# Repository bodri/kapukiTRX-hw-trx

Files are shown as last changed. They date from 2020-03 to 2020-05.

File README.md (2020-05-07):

# Redundant RC transmitter module & 8 channel receiver
RC Receiver and transmitter module using redundant SX1280 RF modules.

The [firmware](https://github.com/bodri/kapukiTRX-fw-trx) is still under development, but you can take a look already...

[Please take a look at my previous project here](https://github.com/bodri/RcReceiver)

# Design
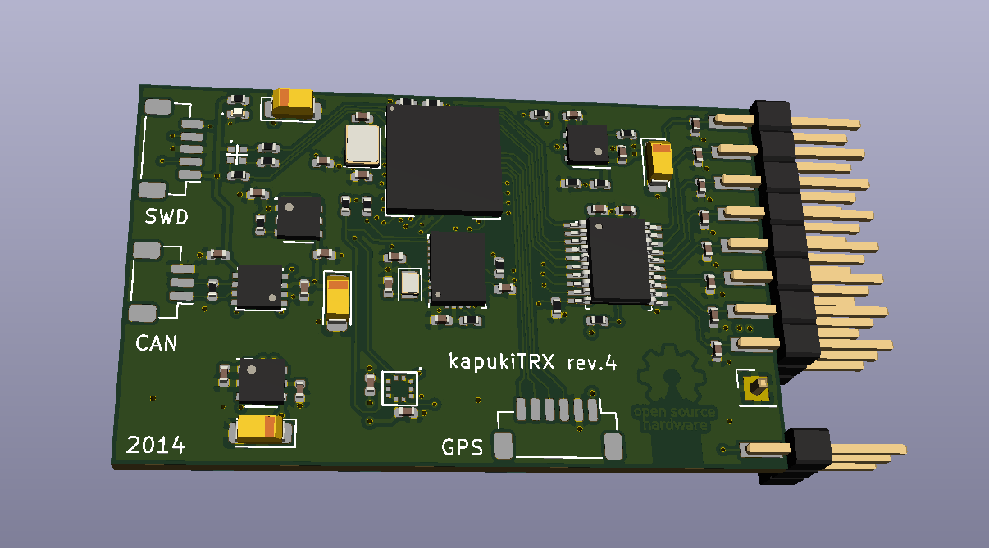
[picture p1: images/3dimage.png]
KiCAD 3D view


# Manufacturing
I would like to compare services from [OSHPark](http://oshpark.com)/[OSH Stencils](https://www.oshstencils.com) and [JLCPCB](http://jlcpcb.com), so I ordered:

| Manufacturer | Items | Price  | Order date | Shipped | Received | Total days |
|---|---|---|---|---|---|---|
| OSHPark | 3 PCBs | $19.80 | 09/11/2019 | 21/11/2019** | 17/12/2019 | 21 (35)**  |
| OSH Stencils | 1 stencil | $21.60 | 09/11/2019 | 12/11/2019 | 19/11/2019 | 10 |
| JLCPCB | 10 PCBs + stencil | $28.33 | 09/11/2019 | 14/11/2019 | 03/12/2019 | 21 |

<sub>** Originally was shipped on 21/11/2019 and received on the same day as the JLCPCB package, but I have received a message that the PCBs have "Severe over-etching in some regions" therefore not to use them. OSHPark refabricated them and I received the second batch on 17/12/2019.<sub>

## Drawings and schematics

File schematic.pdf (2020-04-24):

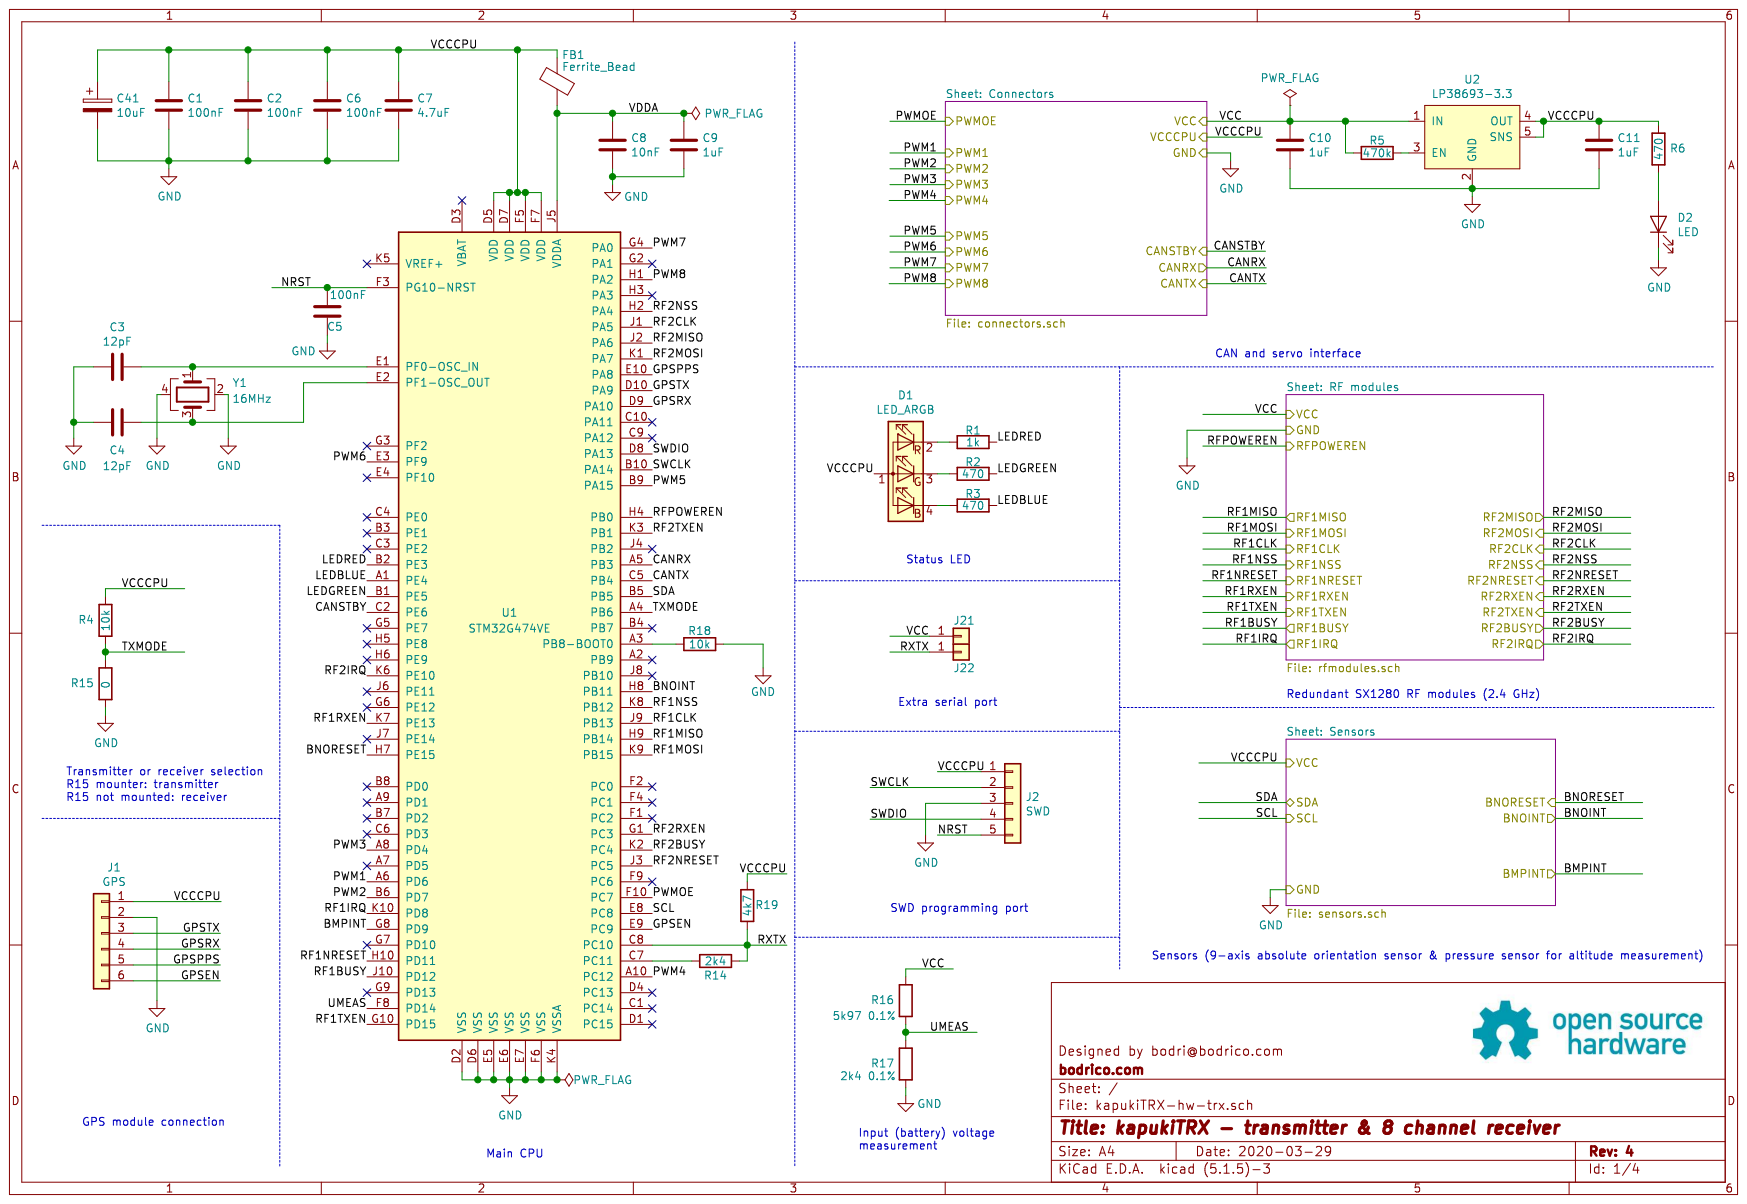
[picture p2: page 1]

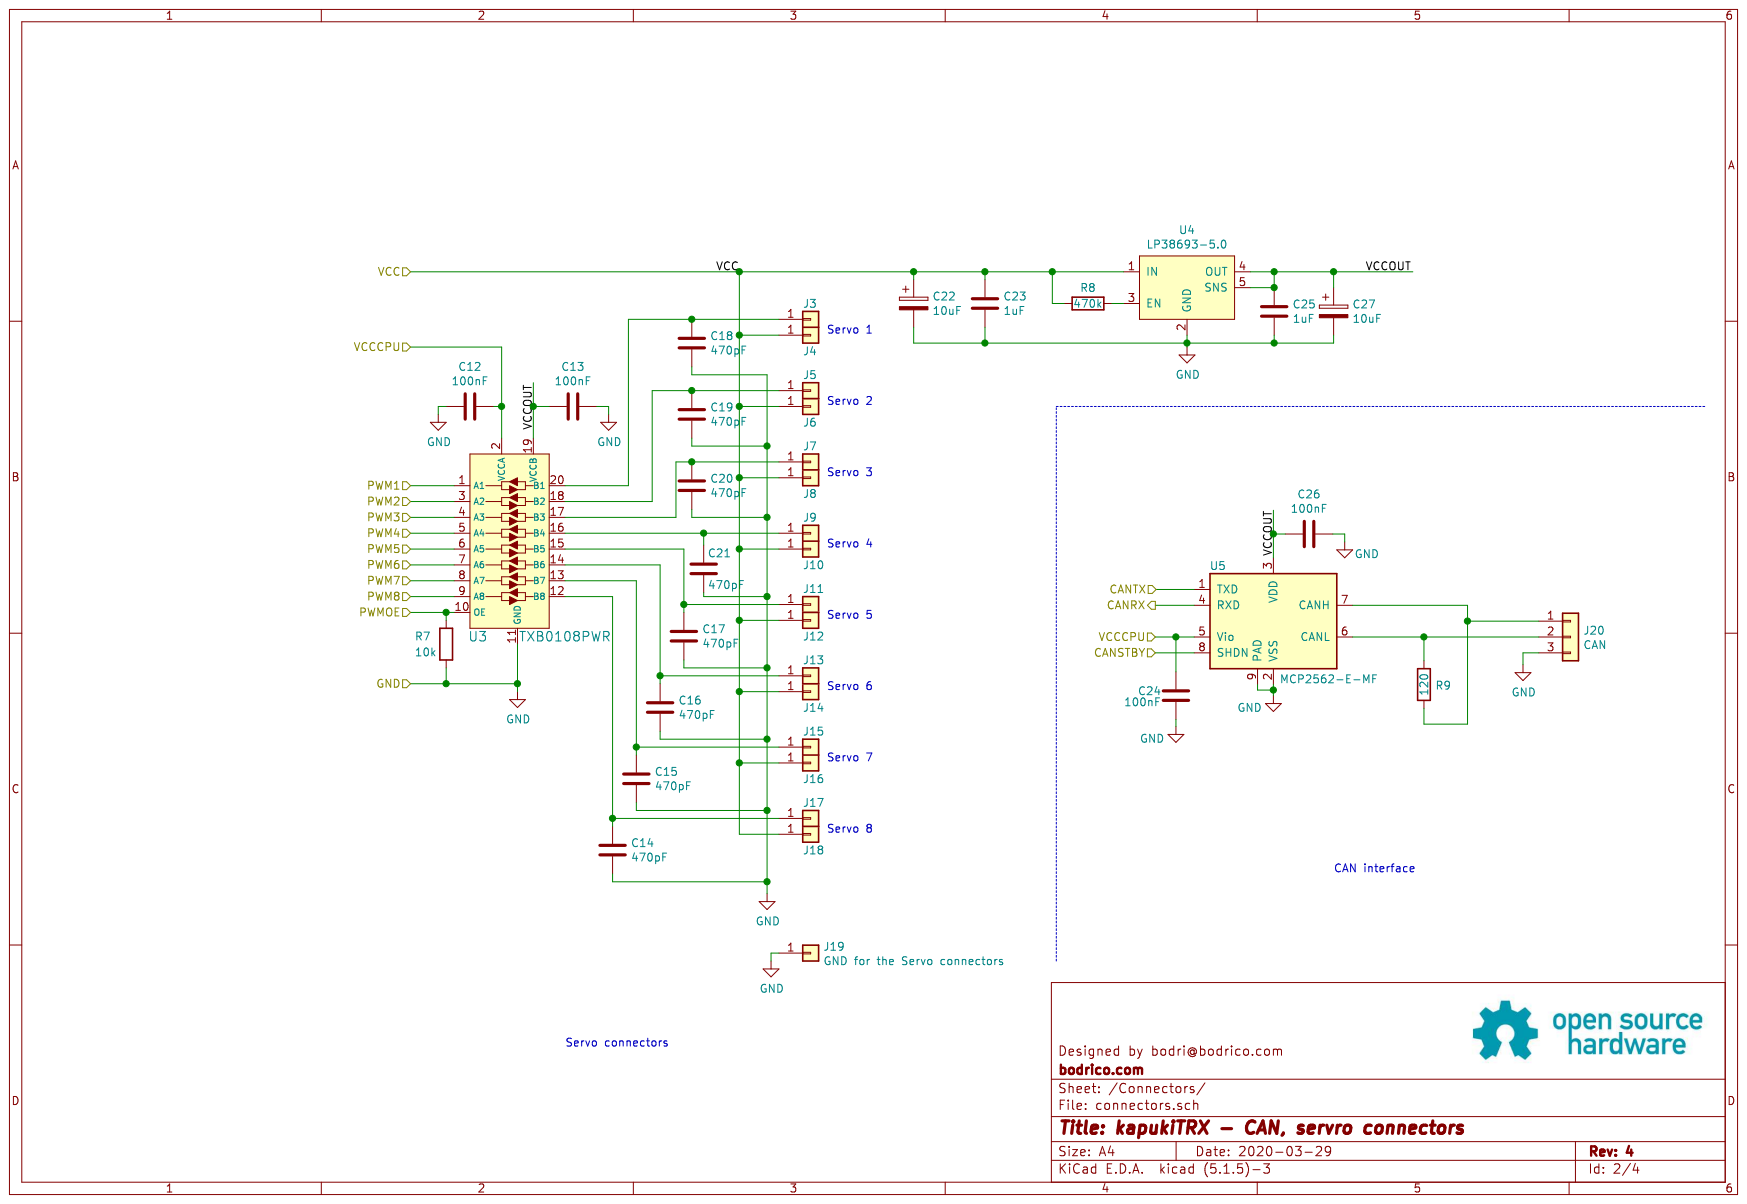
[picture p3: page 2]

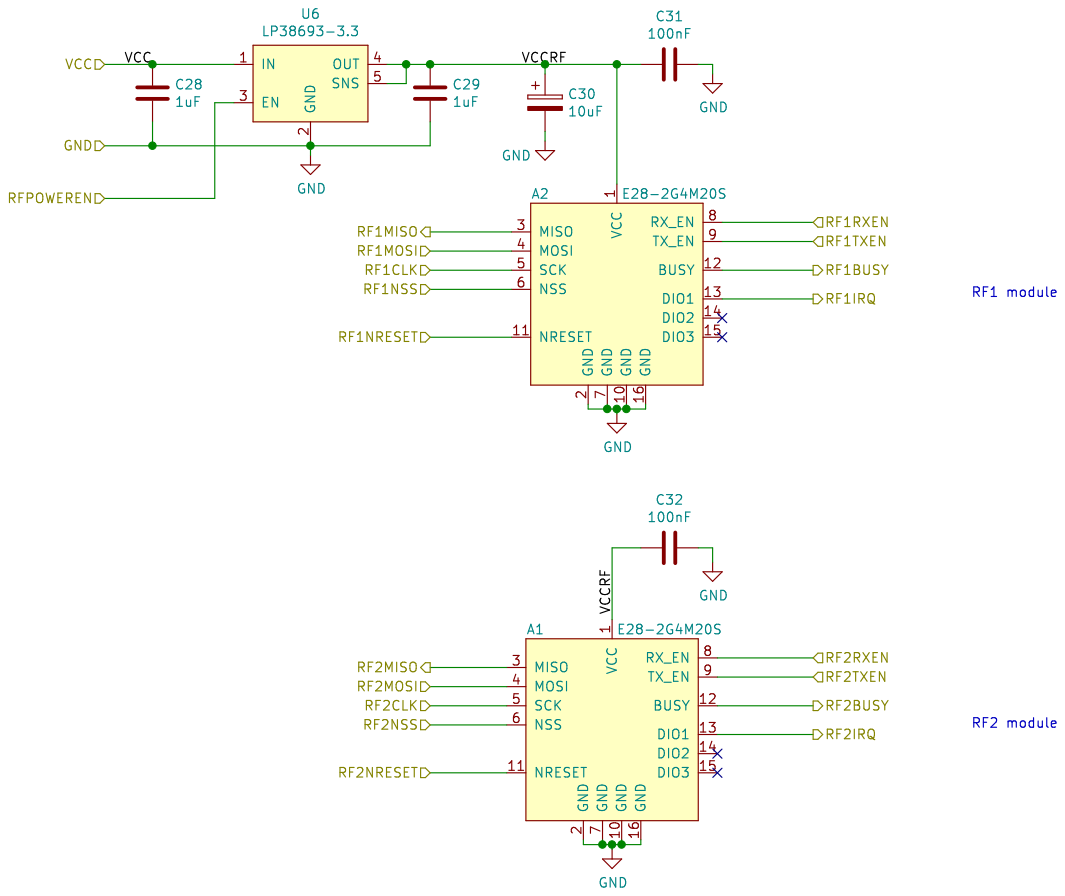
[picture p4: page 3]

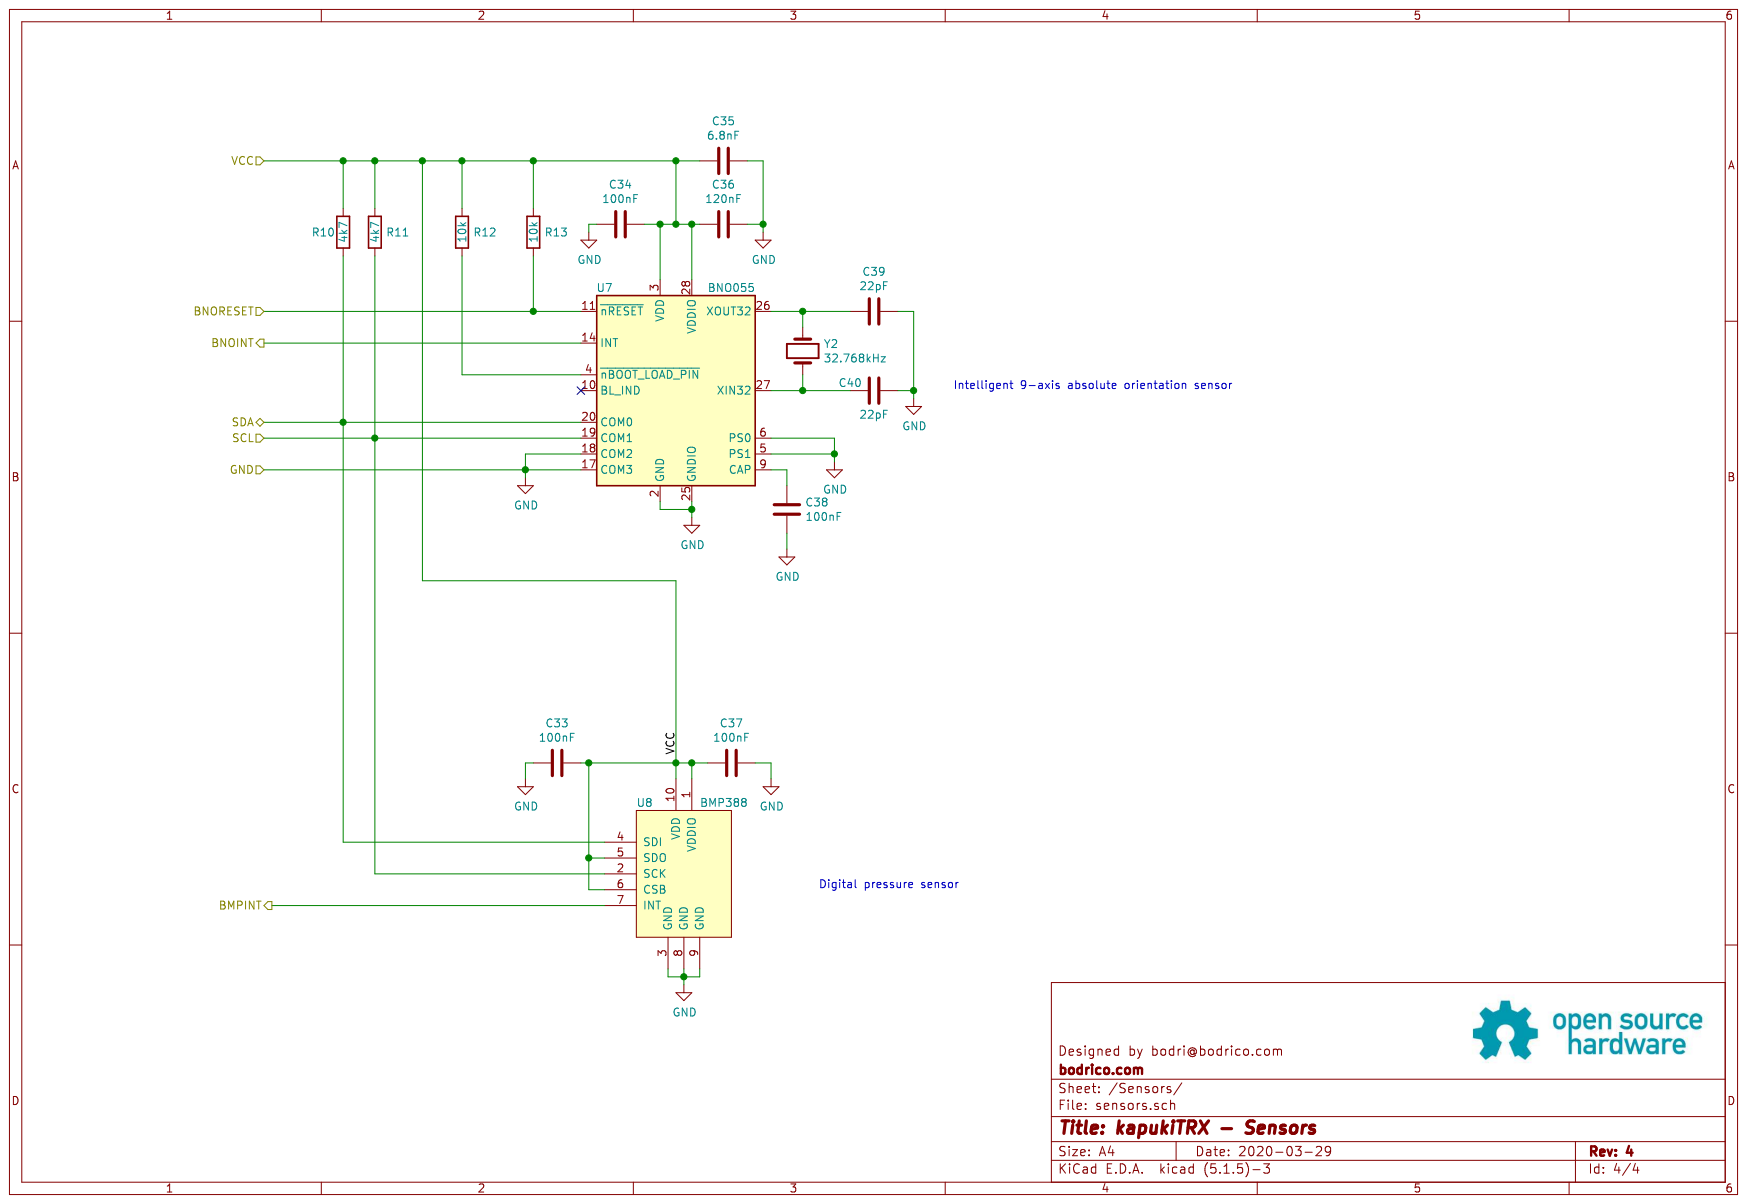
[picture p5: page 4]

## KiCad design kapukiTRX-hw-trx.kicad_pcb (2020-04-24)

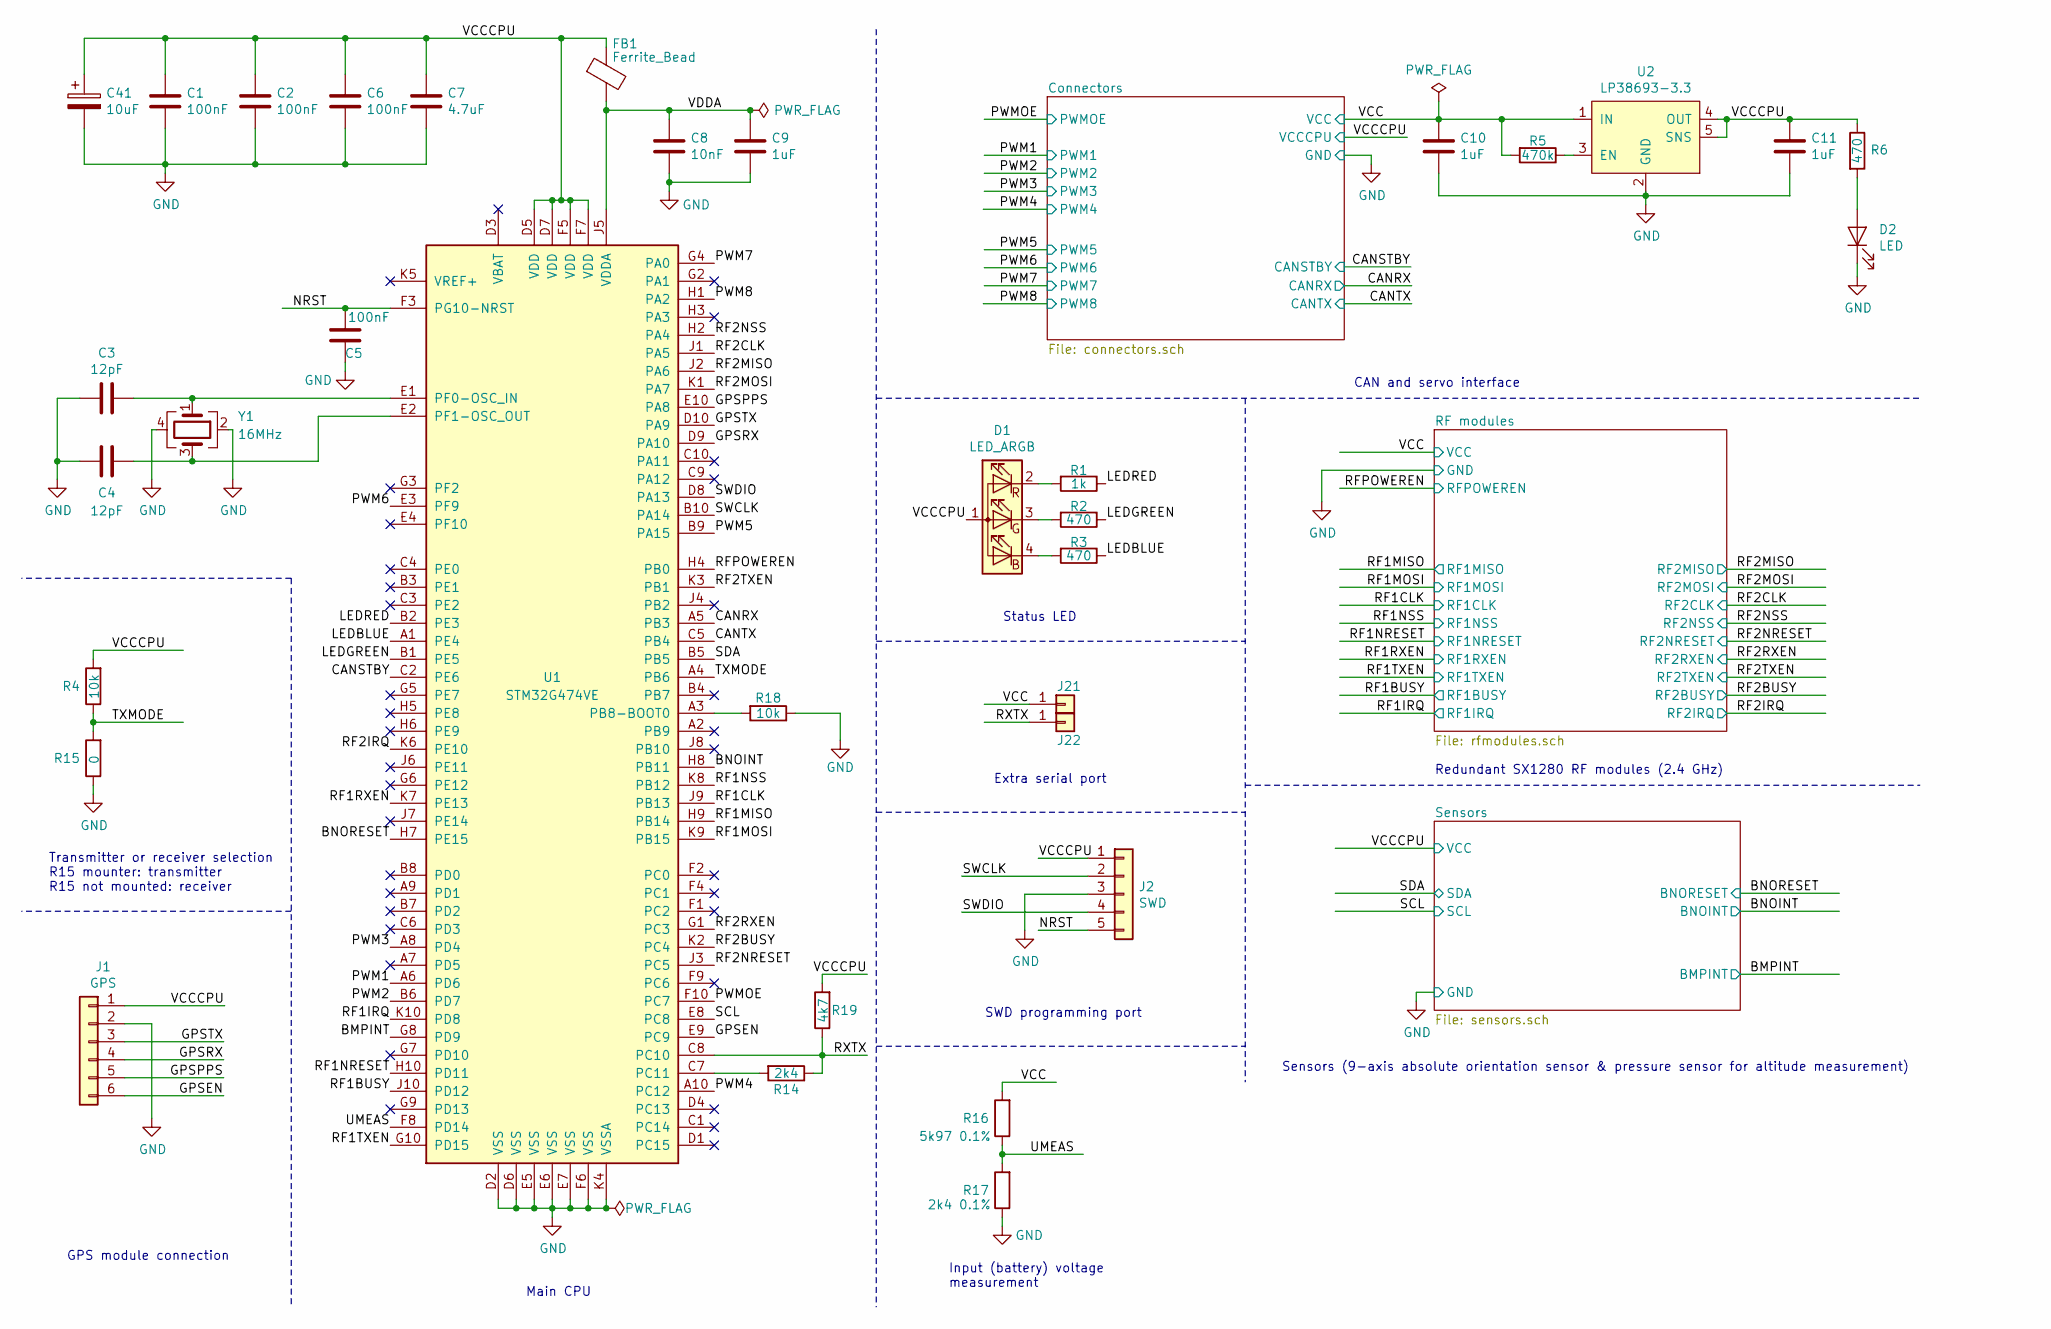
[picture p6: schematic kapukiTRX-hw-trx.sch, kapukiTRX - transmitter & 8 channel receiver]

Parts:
C1, C2, C5, C6: 100nF; C_0402_1005Metric
C3, C4: 12pF; C_0402_1005Metric
C7: 4.7uF; C_0402_1005Metric
C8: 10nF; C_0402_1005Metric
C9, C10, C11: 1uF; C_0402_1005Metric
C41: 10uF; CP_EIA-3216-18_Kemet-A
D1: LED_ARGB; LED_Lumex-LX0404
D2: LED; LED_0402_1005Metric
FB1: Ferrite_Bead; L_0402_1005Metric
J1: GPS; JST_SH_BM06B-SRSS-TB_1x06-1MP_P1.00mm_Vertical
J2: SWD; JST_SH_BM05B-SRSS-TB_1x05-1MP_P1.00mm_Vertical
J21, J22: Conn_01x01; PinHeader_1x01_P1.27mm
R1: 1k; R_0402_1005Metric
R2, R3, R6: 470; R_0402_1005Metric
R4, R18: 10k; R_0402_1005Metric
R5: 470k; R_0402_1005Metric
R14: 2k4; R_0402_1005Metric
R15: 0; R_0402_1005Metric
R16: 5k97 0.1%; R_0402_1005Metric
R17: 2k4 0.1%; R_0402_1005Metric
R19: 4k7; R_0402_1005Metric
U1: STM32G474VE; TFBGA-100_10x10_8.0x8.0mm
U2: LP38693-3.3; WSON-6_3x3mm_Pitch0.95mm
Y1: 16MHz; Oscillator_SMD_SeikoEpson_SG210-4Pin_2.5x2.0mm

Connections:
/BMPINT: U1.G8 (PD9); also elsewhere on the board
/BNOINT: U1.H8 (PB11); also elsewhere on the board
/BNORESET: U1.H7 (PE15); also elsewhere on the board
/CANRX: U1.A5 (PB3); also elsewhere on the board
/CANSTBY: U1.C2 (PE6); also elsewhere on the board
/CANTX: U1.C5 (PB4); also elsewhere on the board
/GPSEN: J1.6, U1.E9 (PC9)
/GPSPPS: J1.5, U1.E10 (PA8)
/GPSRX: J1.4, U1.D9 (PA10)
/GPSTX: J1.3, U1.D10 (PA9)
/LEDBLUE: R3.1, U1.A1 (PE4)
/LEDGREEN: R2.1, U1.B1 (PE5)
/LEDRED: R1.1, U1.B2 (PE3)
/NRST: C5.2, J2.5, U1.F3 (PG10-NRST)
/PWM1: U1.A6 (PD6); also elsewhere on the board
/PWM2: U1.B6 (PD7); also elsewhere on the board
/PWM3: U1.A8 (PD4); also elsewhere on the board
/PWM4: U1.A10 (PC12); also elsewhere on the board
/PWM5: U1.B9 (PA15); also elsewhere on the board
/PWM6: U1.E3 (PF9); also elsewhere on the board
/PWM7: U1.G4 (PA0); also elsewhere on the board
/PWM8: U1.H1 (PA2); also elsewhere on the board
/PWMOE: U1.F10 (PC7); also elsewhere on the board
/RF1BUSY: U1.J10 (PD12); also elsewhere on the board
/RF1CLK: U1.J9 (PB13); also elsewhere on the board
/RF1IRQ: U1.K10 (PD8); also elsewhere on the board
/RF1MISO: U1.H9 (PB14); also elsewhere on the board
/RF1MOSI: U1.K9 (PB15); also elsewhere on the board
/RF1NRESET: U1.H10 (PD11); also elsewhere on the board
/RF1NSS: U1.K8 (PB12); also elsewhere on the board
/RF1RXEN: U1.K7 (PE13); also elsewhere on the board
/RF1TXEN: U1.G10 (PD15); also elsewhere on the board
/RF2BUSY: U1.K2 (PC4); also elsewhere on the board
/RF2CLK: U1.J1 (PA5); also elsewhere on the board
/RF2IRQ: U1.K6 (PE10); also elsewhere on the board
/RF2MISO: U1.J2 (PA6); also elsewhere on the board
/RF2MOSI: U1.K1 (PA7); also elsewhere on the board
/RF2NRESET: U1.J3 (PC5); also elsewhere on the board
/RF2NSS: U1.H2 (PA4); also elsewhere on the board
/RF2RXEN: U1.G1 (PC3); also elsewhere on the board
/RF2TXEN: U1.K3 (PB1); also elsewhere on the board
/RFPOWEREN: U1.H4 (PB0); also elsewhere on the board
/RXTX: J22.1, R14.1, R19.1, U1.C8 (PC10)
/SCL: U1.E8 (PC8); also elsewhere on the board
/SDA: U1.B5; also elsewhere on the board
/SWCLK: J2.2, U1.B10 (PA14)
/SWDIO: J2.4, U1.D8 (PA13)
/TXMODE: R4.1, R15.2, U1.A4 (PB6)
/UMEAS: R16.1, R17.2, U1.F8 (PD14)
/VCCCPU: C1.1, C2.1, C6.1, C7.1, C11.1, C41.1, D1.1 (A), FB1.1, J1.1, J2.1, R4.2, R6.1, R19.2, U1.D5 (VDD), U1.D7 (VDD), U1.F5 (VDD), U1.F7 (VDD), U2.4 (OUT), U2.5 (SNS); also elsewhere on the board
/VDDA: C8.1, C9.1, FB1.2, U1.J5 (VDDA)
GND: C1.2, C2.2, C3.2, C4.2, C5.1, C6.2, C7.2, C8.2, C9.2, C10.2, C11.2, C41.2, D2.1 (K), J1.2, J2.3, R15.1, R17.1, R18.1, U1.D2 (VSS), U1.D6 (VSS), U1.E5 (VSS), U1.E6 (VSS), U1.E7 (VSS), U1.F6 (VSS), U1.K4 (VSSA), U2.2 (GND), U2.7 (GND), Y1.2, Y1.4; also elsewhere on the board
IN: C10.1, J21.1, R5.2, R16.2, U2.1 (IN), U2.6 (IN); also elsewhere on the board
unnamed: C3.1, U1.E1 (PF0-OSC_IN), Y1.1
unnamed: C4.1, U1.E2 (PF1-OSC_OUT), Y1.3
unnamed: D1.2 (RK), R1.2
unnamed: D1.3 (GK), R2.2
unnamed: D1.4 (BK), R3.2
unnamed: D2.2 (A), R6.2
unnamed: R5.1, U2.3 (EN)
unnamed: R14.2, U1.C7 (PC11)
unnamed: R18.2, U1.A3 (PB8-BOOT0)

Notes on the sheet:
Status LED
Extra serial port
SWD programming port
Redundant SX1280 RF modules (2.4 GHz)
Sensors (9-axis absolute orientation sensor & pressure sensor for altitude measurement)
Transmitter or receiver selection R15 mounter: transmitter R15 not mounted: receiver
GPS module connection
CAN and servo interface
Main CPU
Input (battery) voltage measurement

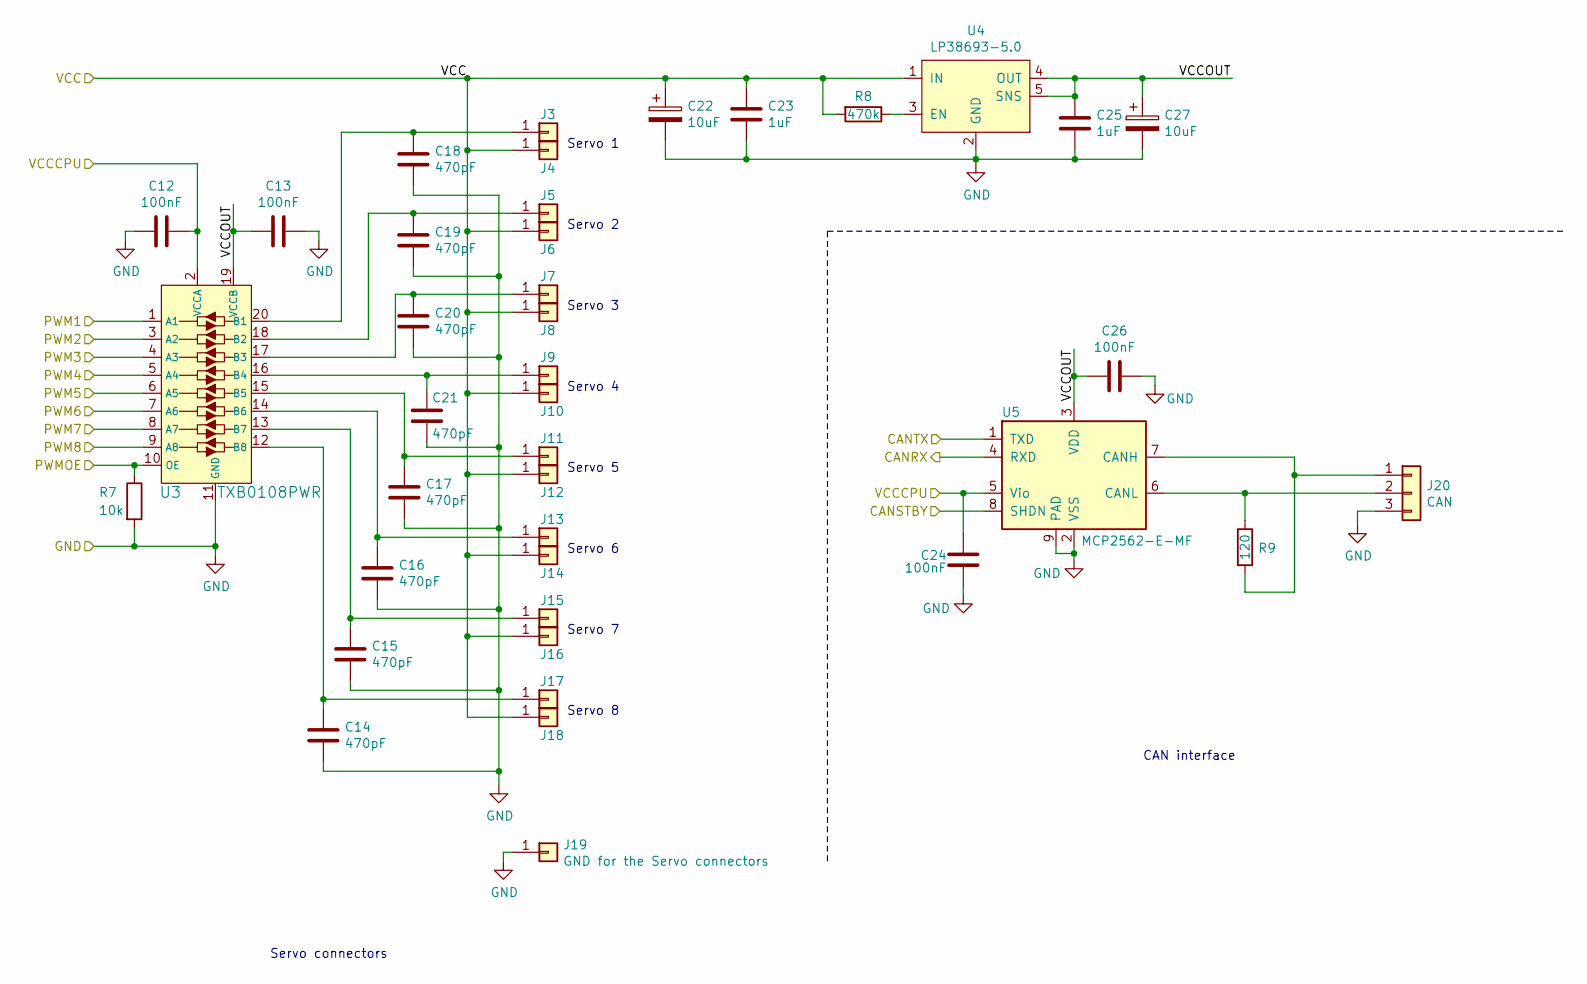
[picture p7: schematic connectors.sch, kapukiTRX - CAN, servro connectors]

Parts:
C12, C13, C24, C26: 100nF; C_0402_1005Metric
C14, C15, C16, C17, C18, C19, C20, C21: 470pF; C_0402_1005Metric
C22, C27: 10uF; CP_EIA-3216-18_Kemet-A
C23, C25: 1uF; C_0402_1005Metric
J3, J4, J5, J6, J7, J8, J9, J10, J11, J12, J13, J14, J15, J16, J17, J18: Conn_01x01; PinHeader_1x01_P1.27mm
J19: GND for the Servo connectors; PinHeader_1x01_P2.54mm_Vertical
J20: CAN; JST_SH_BM03B-SRSS-TB_1x03-1MP_P1.00mm_Vertical
R7: 10k; R_0402_1005Metric
R8: 470k; R_0402_1005Metric
R9: 120; R_0402_1005Metric
U3: TXB0108PWR; TSSOP-20_W4.4mm; MPN TXB0108PWR; Digi-Key_PN 296-21527-1-ND
U4: LP38693-5.0; WSON-6_3x3mm_Pitch0.95mm
U5: MCP2562-E-MF; DFN-8-1EP_3x3mm_P0.65mm_EP1.55x2.4mm

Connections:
/CANRX: U5.4 (RXD); also elsewhere on the board
/CANSTBY: U5.8 (SHDN); also elsewhere on the board
/CANTX: U5.1 (TXD); also elsewhere on the board
/Connectors/VCCOUT: C13.2, C25.1, C26.2, C27.1, U3.19 (VCCB), U4.4 (OUT), U4.5 (SNS), U5.3 (VDD)
/PWM1: U3.1 (A1); also elsewhere on the board
/PWM2: U3.3 (A2); also elsewhere on the board
/PWM3: U3.4 (A3); also elsewhere on the board
/PWM4: U3.5 (A4); also elsewhere on the board
/PWM5: U3.6 (A5); also elsewhere on the board
/PWM6: U3.7 (A6); also elsewhere on the board
/PWM7: U3.8 (A7); also elsewhere on the board
/PWM8: U3.9 (A8); also elsewhere on the board
/PWMOE: R7.1, U3.10 (OE); also elsewhere on the board
/VCCCPU: C12.1, C24.2, U3.2 (VCCA), U5.5 (Vio); also elsewhere on the board
GND: C12.2, C13.1, C14.2, C15.2, C16.2, C17.2, C18.2, C19.2, C20.2, C21.2, C22.2, C23.2, C24.1, C25.2, C26.1, C27.2, J19.1, J20.3, R7.2, U3.11 (GND), U4.2 (GND), U4.7 (GND), U5.2 (VSS), U5.9 (PAD); also elsewhere on the board
IN: C22.1, C23.1, J4.1, J6.1, J8.1, J10.1, J12.1, J14.1, J16.1, J18.1, R8.2, U4.1 (IN), U4.6 (IN); also elsewhere on the board
unnamed: C14.1, J17.1, U3.12 (B8)
unnamed: C15.1, J15.1, U3.13 (B7)
unnamed: C16.1, J13.1, U3.14 (B6)
unnamed: C17.1, J11.1, U3.15 (B5)
unnamed: C18.1, J3.1, U3.20 (B1)
unnamed: C19.1, J5.1, U3.18 (B2)
unnamed: C20.1, J7.1, U3.17 (B3)
unnamed: C21.1, J9.1, U3.16 (B4)
unnamed: J20.1, R9.2, U5.7 (CANH)
unnamed: J20.2, R9.1, U5.6 (CANL)
unnamed: R8.1, U4.3 (EN)

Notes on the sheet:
Servo 1
Servo 2
Servo 3
Servo 4
Servo 5
Servo 6
Servo 7
Servo 8
CAN interface
Servo connectors

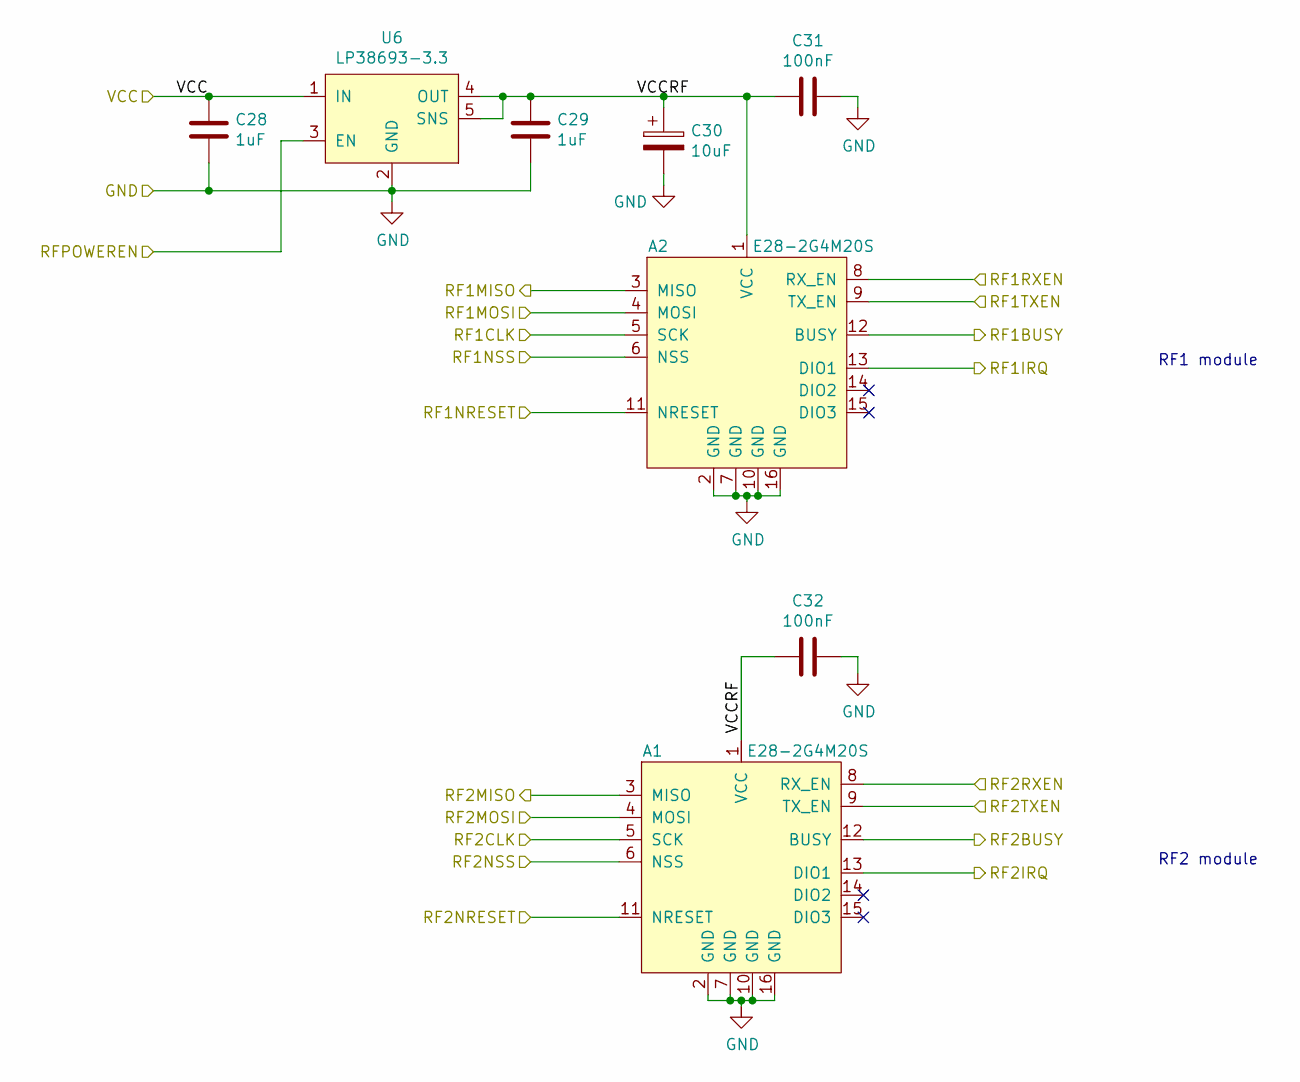
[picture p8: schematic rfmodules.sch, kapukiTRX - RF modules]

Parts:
A1, A2: E28-2G4M20S
C28, C29: 1uF; C_0402_1005Metric
C30: 10uF; CP_EIA-3216-18_Kemet-A
C31, C32: 100nF; C_0402_1005Metric
U6: LP38693-3.3; WSON-6_3x3mm_Pitch0.95mm

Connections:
/RF1BUSY: A2.12 (BUSY); also elsewhere on the board
/RF1CLK: A2.5 (SCK); also elsewhere on the board
/RF1IRQ: A2.13 (DIO1); also elsewhere on the board
/RF1MISO: A2.3 (MISO); also elsewhere on the board
/RF1MOSI: A2.4 (MOSI); also elsewhere on the board
/RF1NRESET: A2.11 (NRESET); also elsewhere on the board
/RF1NSS: A2.6 (NSS); also elsewhere on the board
/RF1RXEN: A2.8 (RX_EN); also elsewhere on the board
/RF1TXEN: A2.9 (TX_EN); also elsewhere on the board
/RF2BUSY: A1.12 (BUSY); also elsewhere on the board
/RF2CLK: A1.5 (SCK); also elsewhere on the board
/RF2IRQ: A1.13 (DIO1); also elsewhere on the board
/RF2MISO: A1.3 (MISO); also elsewhere on the board
/RF2MOSI: A1.4 (MOSI); also elsewhere on the board
/RF2NRESET: A1.11 (NRESET); also elsewhere on the board
/RF2NSS: A1.6 (NSS); also elsewhere on the board
/RF2RXEN: A1.8 (RX_EN); also elsewhere on the board
/RF2TXEN: A1.9 (TX_EN); also elsewhere on the board
/RF modules/VCCRF: A1.1 (VCC), A2.1 (VCC), C29.1, C30.1, C31.2, C32.2, U6.4 (OUT), U6.5 (SNS)
/RFPOWEREN: U6.3 (EN); also elsewhere on the board
GND: A1.2 (GND), A1.7 (GND), A1.10 (GND), A1.16 (GND), A2.2 (GND), A2.7 (GND), A2.10 (GND), A2.16 (GND), C28.2, C29.2, C30.2, C31.1, C32.1, U6.2 (GND), U6.7 (GND); also elsewhere on the board
IN: C28.1, U6.1 (IN), U6.6 (IN); also elsewhere on the board

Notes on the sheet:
RF1 module
RF2 module

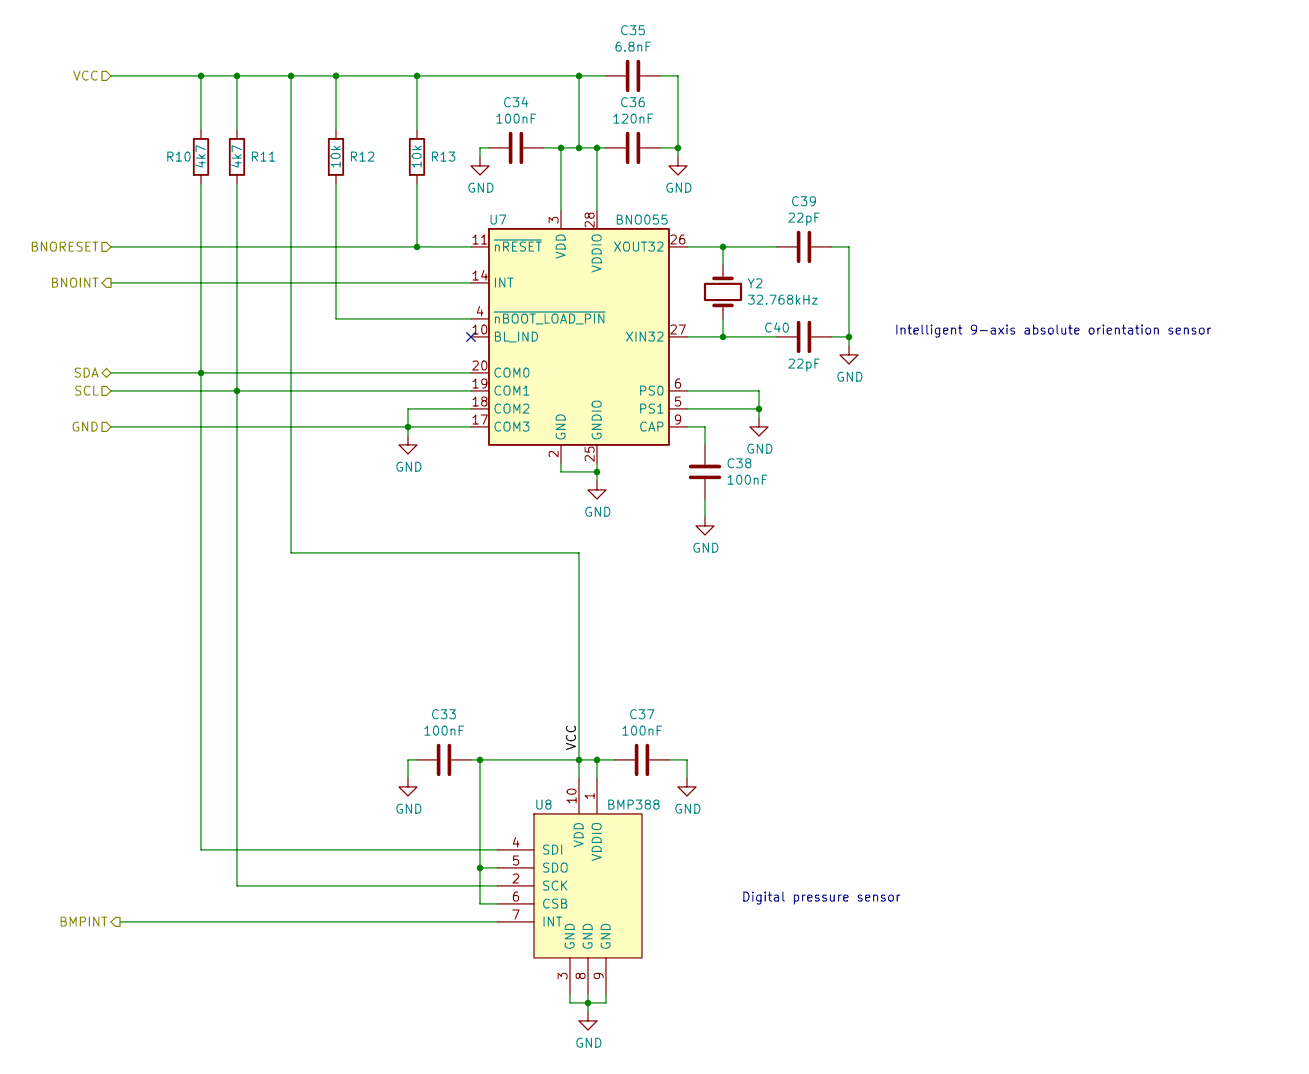
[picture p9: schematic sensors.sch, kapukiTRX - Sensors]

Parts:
C33, C34, C37, C38: 100nF; C_0402_1005Metric
C35: 6.8nF; C_0402_1005Metric
C36: 120nF; C_0402_1005Metric
C39, C40: 22pF; C_0402_1005Metric
R10, R11: 4k7; R_0402_1005Metric
R12, R13: 10k; R_0402_1005Metric
U7: BNO055; LGA-28_5.2x3.8mm_P0.5mm
U8: BMP388; Bosch_LGA10_2x2mm_Pitch0.5mm
Y2: 32.768kHz; Crystal_SMD_2012-2Pin_2.0x1.2mm

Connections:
/BMPINT: U8.7 (INT); also elsewhere on the board
/BNOINT: U7.14 (INT); also elsewhere on the board
/BNORESET: R13.2, U7.11 (~nRESET); also elsewhere on the board
/SCL: R11.2, U7.19 (COM1), U8.2 (SCK); also elsewhere on the board
/SDA: R10.2, U7.20 (COM0), U8.4 (SDI); also elsewhere on the board
/VCCCPU: C33.1, C34.1, C35.2, C36.2, C37.2, R10.1, R11.1, R12.1, R13.1, U7.3 (VDD), U7.28 (VDDIO), U8.1 (VDDIO), U8.5 (SDO), U8.6 (CSB), U8.10 (VDD); also elsewhere on the board
GND: C33.2, C34.2, C35.1, C36.1, C37.1, C38.2, C39.1, C40.1, U7.2 (GND), U7.5 (PS1), U7.6 (PS0), U7.15 (GNDIO), U7.16 (GNDIO), U7.17 (COM3), U7.18 (COM2), U7.25 (GNDIO), U8.3 (GND), U8.8 (GND), U8.9 (GND); also elsewhere on the board
unnamed: C38.1, U7.9 (CAP)
unnamed: C39.2, U7.26 (XOUT32), Y2.1
unnamed: C40.2, U7.27 (XIN32), Y2.2
unnamed: R12.2, U7.4 (~nBOOT_LOAD_PIN)

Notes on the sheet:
Digital pressure sensor
Intelligent 9-axis absolute orientation sensor

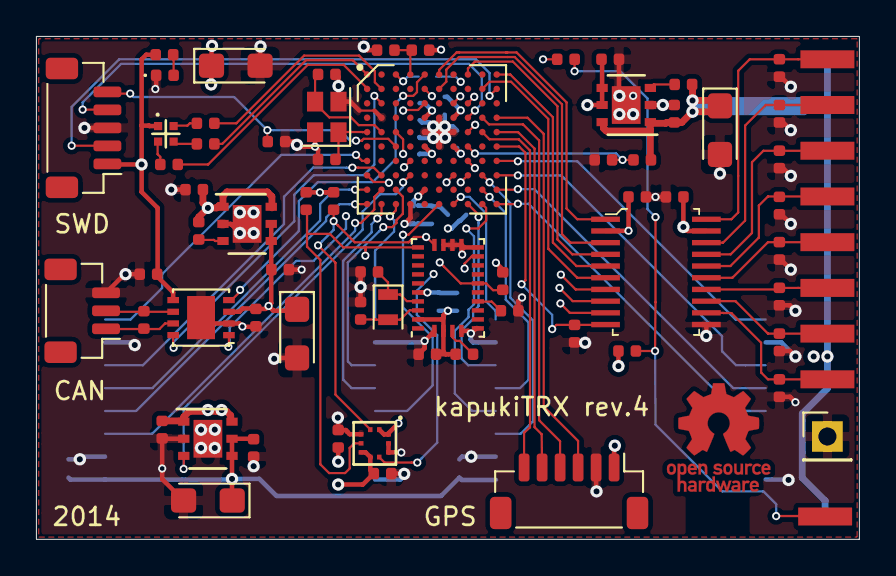
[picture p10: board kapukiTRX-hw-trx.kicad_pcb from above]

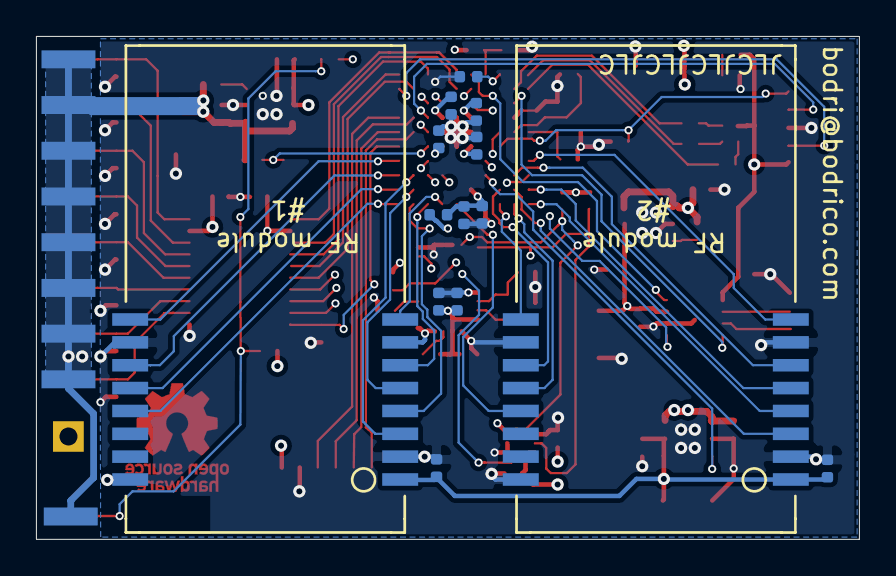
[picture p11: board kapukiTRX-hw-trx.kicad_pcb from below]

Board: 4 copper layers, 45.7 x 27.9 mm, 97 parts (23 on the bottom side), 79 nets.

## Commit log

2019-10-27 Use it on mac
    [connectors.sch, kapukiTRX-hw-trx.sch, rfmodules.sch]
2019-10-27 Revert "Use it on mac"
    This reverts commit 31182a4bd36aa13d038d509ee2b2cd4b0d770585.
    [connectors.sch, kapukiTRX-hw-trx.sch, rfmodules.sch]
2019-10-29 Add sensors (altitude/9 axis orientation)
    [connectors.sch, kapukiTRX-hw-trx.sch, rfmodules.sch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]
2019-10-29 Wiring sensors
    [kapukiTRX-hw-trx.sch, sensors.sch]
2019-10-29 Use crystal with smaller footprint
    [kapukiTRX-hw-trx.kicad_pcb, sensors.sch]
2019-10-31 Change processor to G4 series
    [kapukiTRX-hw-trx.kicad_pcb, kapukiTRX-hw-trx.sch]
2019-11-02 Placing components and start routing
    [kapukiTRX-hw-trx.kicad_pcb, kapukiTRX-hw-trx.sch]
2019-11-05 Add nets more nets
    [kapukiTRX-hw-trx.kicad_pcb, kapukiTRX-hw-trx.sch]
2019-11-05 Change some pins for better routing
    [kapukiTRX-hw-trx.kicad_pcb, kapukiTRX-hw-trx.sch]
2019-11-08 Add proper footprint for BMP388
    [kapukiTRX-hw-trx.kicad_pcb, kapukiTRX-hw-trx.sch, sensors.sch]
2019-11-08 Small changes
    [kapukiTRX-hw-trx.kicad_pcb]
2019-11-08 Make sure that wires underneath the BGA goes middle between pins
    [kapukiTRX-hw-trx.kicad_pcb]
2019-11-08 Swap pwm lines for better routing
    [kapukiTRX-hw-trx.sch]
2019-11-08 Almost finish routing
    [kapukiTRX-hw-trx.kicad_pcb]
2019-11-08 Finish routing
    [kapukiTRX-hw-trx.kicad_pcb]
2019-11-09 Add support for EX bus
    [connectors.sch, kapukiTRX-hw-trx.sch, rfmodules.sch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]
2019-11-09 Routing for EX bus
    [kapukiTRX-hw-trx.kicad_pcb]
2019-11-09 Change name of sheets
    [connectors.sch, kapukiTRX-hw-trx.sch, rfmodules.sch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]
2019-11-09 Add an elec cap to cup rail
    [kapukiTRX-hw-trx.kicad_pcb, kapukiTRX-hw-trx.sch]
2019-11-09 Add Open hardware logo
    [kapukiTRX-hw-trx.kicad_pcb]
2019-11-09 Final version
    [kapukiTRX-hw-trx.kicad_pcb]
2019-11-10 Add 3D view
    [kapukiTRX-hw-trx.kicad_pcb]
2019-11-10 Add schematic.pdf
2019-11-15 Fix connector placing
    [kapukiTRX-hw-trx.kicad_pcb]
2019-11-22 PCB shipped from OSHPark
2019-12-03 PCBs have been landed
2019-12-19 PCBs are received from OSHPark
2020-01-01 Fix BMP388 footprint issue
    [connectors.sch, kapukiTRX-hw-trx.kicad_pcb, kapukiTRX-hw-trx.sch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]
2020-01-03 Final changes for rev.3
    [connectors.sch, kapukiTRX-hw-trx.kicad_pcb, kapukiTRX-hw-trx.sch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]
2020-03-29 Add boot resistor, and fix CAN RX pin
    [connectors.sch, kapukiTRX-hw-trx.kicad_pcb, kapukiTRX-hw-trx.sch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]
2020-03-29 Add pull-up for uart
    [connectors.sch, kapukiTRX-hw-trx.kicad_pcb, kapukiTRX-hw-trx.sch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]
2020-03-30 rev.4 sent to JLCPCB
    [kapukiTRX-hw-trx-B_Cu.gbl, kapukiTRX-hw-trx-B_Mask.gbs, kapukiTRX-hw-trx-B_Paste.gbp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]
2020-04-24 Add interactive bom
2020-04-24 Make some value changes for consistency
    [connectors.sch, kapukiTRX-hw-trx.kicad_pcb, kapukiTRX-hw-trx.sch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]
2020-04-24 Remove R18 from silk
    [kapukiTRX-hw-trx.kicad_pcb]
2020-04-24 Add OSH logo and update schematic.pdf
    [connectors.sch, kapukiTRX-hw-trx.sch, rfmodules.sch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]
